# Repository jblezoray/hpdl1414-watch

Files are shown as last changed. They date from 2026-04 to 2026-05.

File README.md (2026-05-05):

# HPDL-1414 Watch

A minimalist watch built around an [HPDL-1414](https://www.datasheetarchive.com/HPDL-1414-datasheet.html) 4-character alphanumeric display, driven by an ATmega32 microcontroller.

If you're brave enougth, you'll find anything you need to build it yourself in this repo.

watch picture

There is a demo of the watch on youtube:

Watch demo video (https://www.youtube.com/watch?v=RL6VkV0jNk0)

## Hardware

| Component | Details |
| --- | --- |
| MCU | atmega328p |
| Display | HPDL-1414 (4 × 16-segment alphanumeric) |
| RTC | DS3231 (I2C) |
| Storage | EEPROM (SPI) |
| Input | 2 buttons |

You'll also need:

- A 3D printer for the case,
- A provider for the HPDL1414 displays. Aliexpress is a good source.
- I ordered the pcbs from jlcpcb. I chose to solder everything myself, but I think it'd be more reasonnable to order with all the components already soldered, except the display as they don't list it.

## Features

- Time display with configurable transitions
- Adjustable luminosity (stored in EEPROM)
- Low-power screen-off state
- State machine architecture

## Project Structure

```
hpdl-1414.ino          # Main sketch
src/
  screen-hpdl1414/     # HPDL-1414 driver
  rtc-ds3231/          # DS3231 RTC driver
  button/              # Button handler
  blinker/             # LED blinker
  persist-configuration/ # EEPROM persistence
  vcc-controller/      # Power control
  states/              # State machine
  pins.h               # Pin definitions
3dmodels/              # Model for the 3D printed case
```

## Watch PCB schematics

Open the schematics (`pcb/hpdl1414/hpdl1414.kicad_sch` and `pcb/hpdl1414/hpdl1414.kicad_pcb`) with [kicad 9.0.1](https://www.kicad.org/).

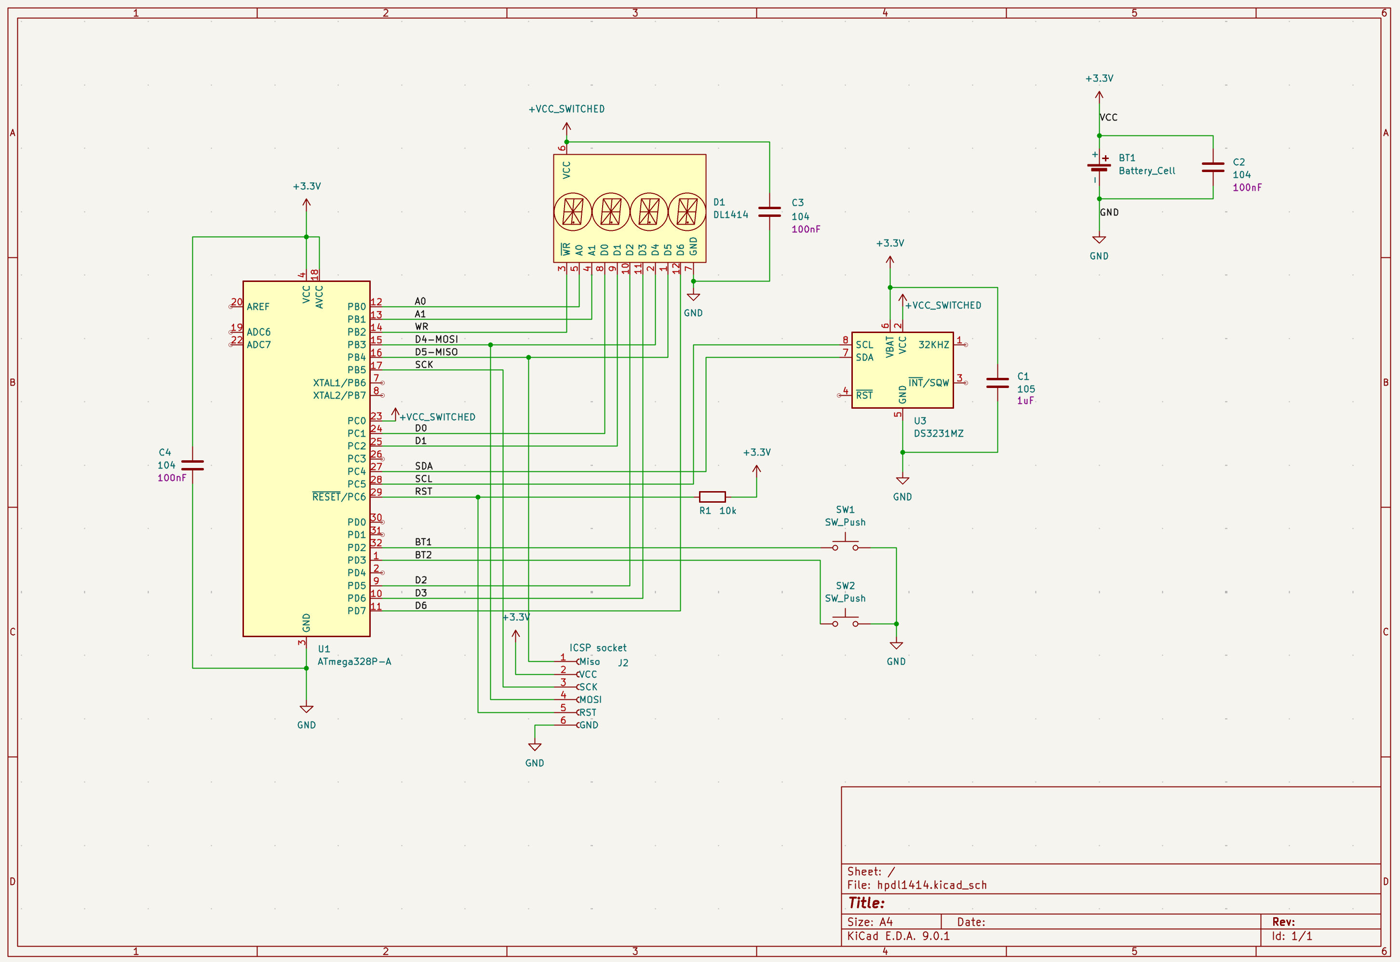
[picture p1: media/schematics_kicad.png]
schematics kicad

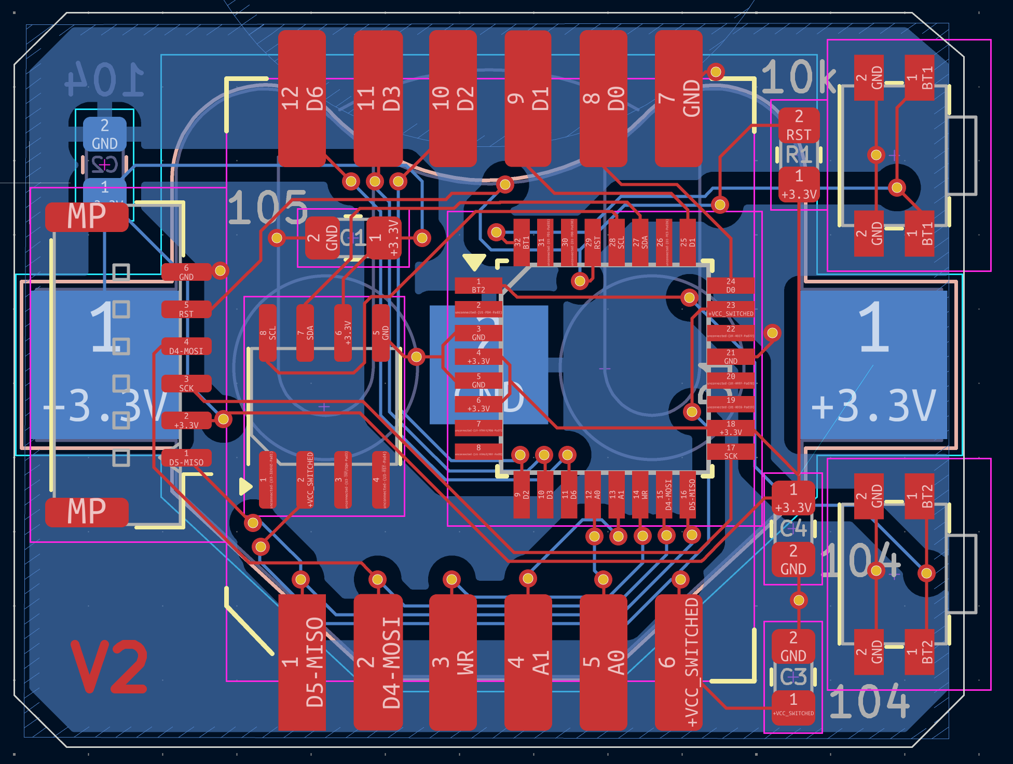
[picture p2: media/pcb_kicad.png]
pcb kicad


Here is the first prototype of the PCB I made. It offers a full view of all the components on one side:
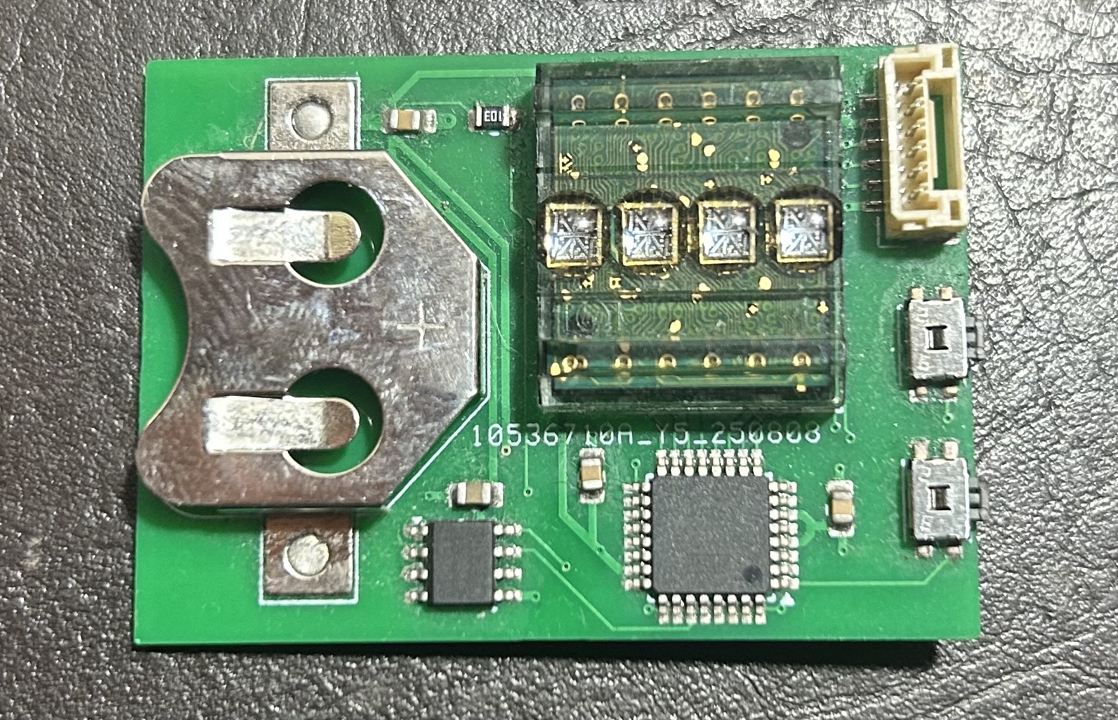
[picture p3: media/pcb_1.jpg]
pcb v1


And here is the final one that is in the watch. It is much smaller:
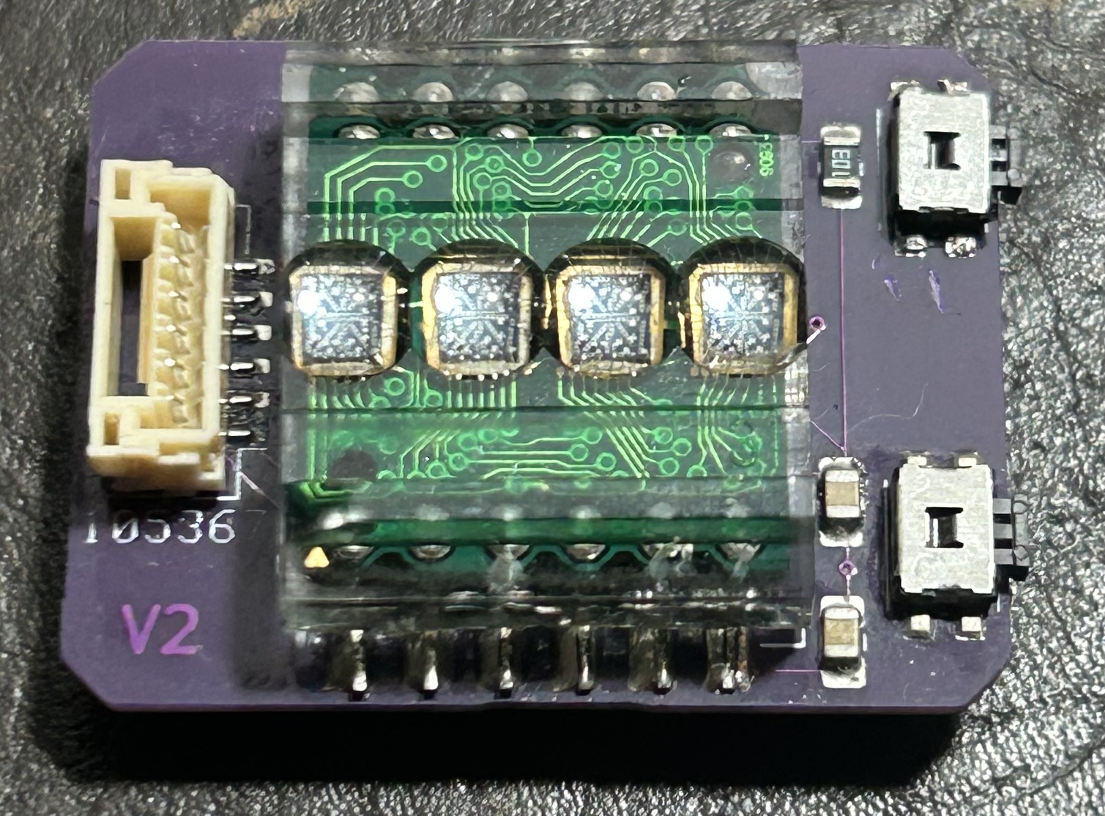
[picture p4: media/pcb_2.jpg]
pcb v2


## Watch case

Open ‘3dmodels/HPDL1414-watch-round.FCStd‘ with [FreeCAD 1.0.2](https://www.freecad.org/). Export it part by part, and print it with your favorite 3d printer. I have great results with a [Bambu lab A1 mini](https://bambulab.com/en-eu/a1-mini).

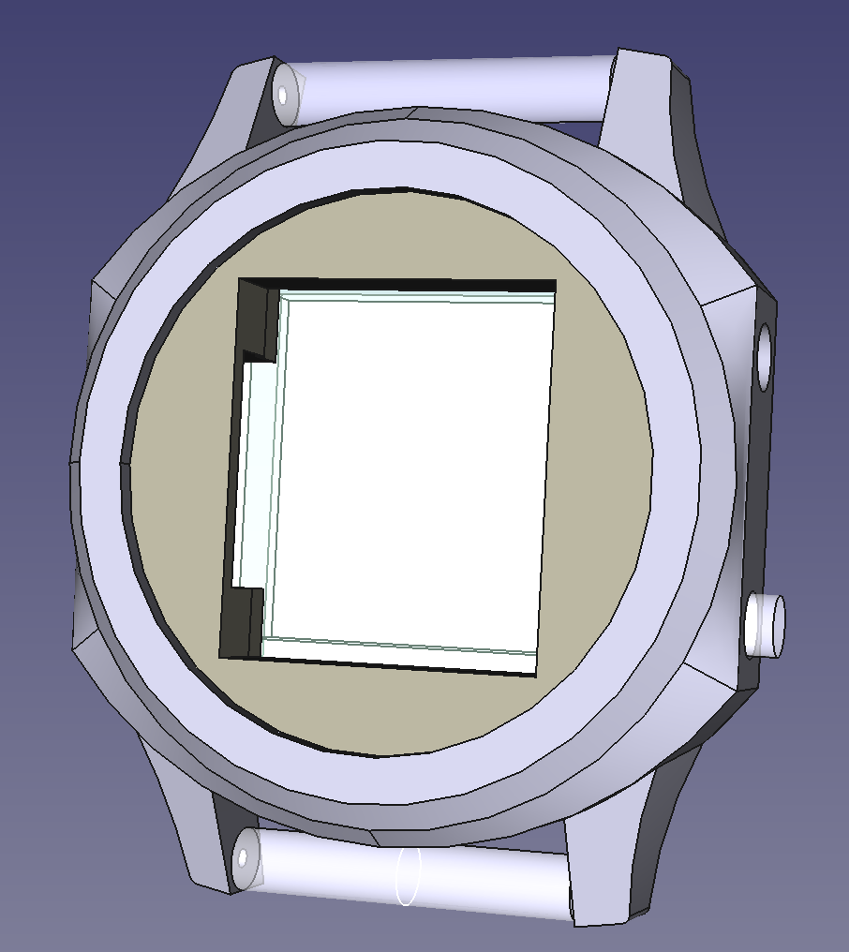
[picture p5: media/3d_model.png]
watch 3d model


You'll have to use threaded inserts, and M1.5 screws to bolt the back of the case:
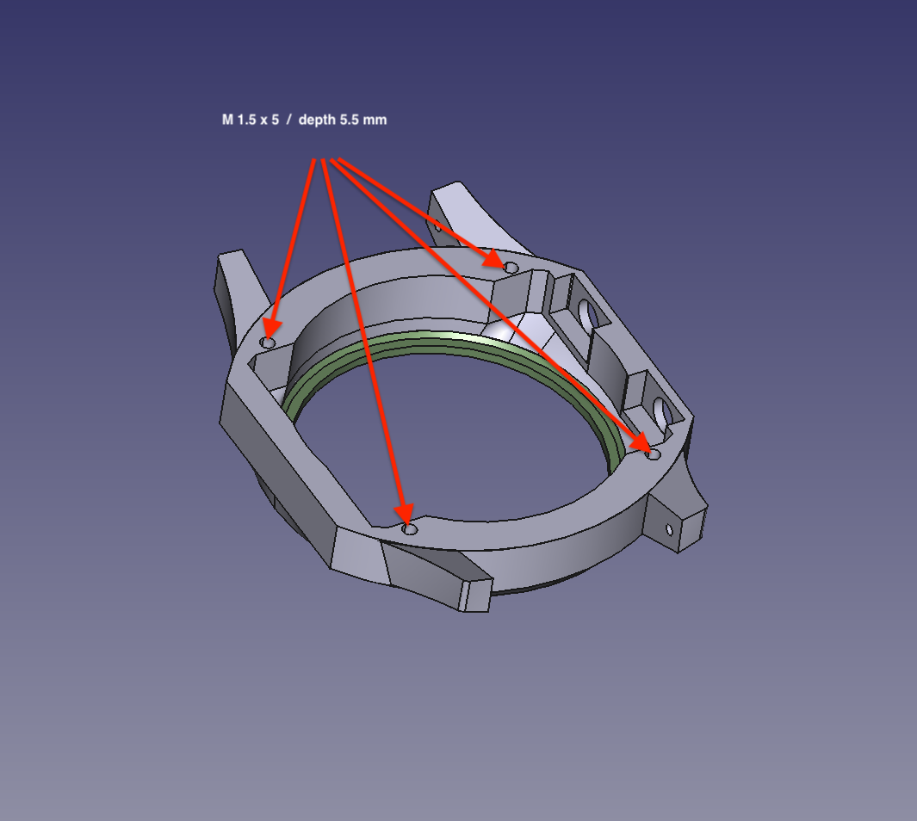
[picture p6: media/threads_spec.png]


## Watch software

I used a Mac for developping this project, but it should work with little to no adjustement on linux. Sorry Windows users, you're on your own on this one.

Also, I find the Arduino IDE really bad, but their libs are ok. So only their CLI is needed. Once installed, everything can be handled by the Makefile.

### Prerequisites

- [Arduino CLI](https://arduino.github.io/arduino-cli/latest/installation/)
- An Arduino board used as ISP programmer (e.g. Uno)

```bash
# Install Arduino CLI (macOS)
$ brew install arduino-cli
$ arduino-cli core install arduino:avr
```

For reference:

```bash
$ arduino-cli version
arduino-cli  Version: 1.4.1 Commit: Homebrew Date: 2026-01-19T16:11:40Z
$ ${HOME}/Library/Arduino15/packages/arduino/tools/avrdude/8.0.0-arduino1/bin/avrdude -v
Avrdude version 8.0-arduino.1
```

### Setup

Copy `config.mk.example` to `config.mk` and fill in your values:

```makefile
ARDUINO_ROOT="/path/to/Arduino15/packages/arduino"  # e.g. ~/Library/Arduino15/packages/arduino
ARDUINO_CLI="/path/to/arduino-cli"
FQBN=arduino:avr:uno      # FQBN of the ISP programmer board
PORT=/dev/cu.usbmodem...  # port of the ISP programmer (make list-devices)
```

### Prepare an arduino to use as an ISP programmer

Plug the board to your computer and run:

```bash
# Flash the ISP programmer
make flash-isp-programmer
```

Now the board can be used as an ISP programmer.

### Plug the watch board to the ISP

IMPORTANT: Remove the battery from the watch board before pluging it!

Plug the ISP and the watch board:

- Arduino ground to GND on the watch board
- PIN 10 to RST
- PIN 11 to MOSI
- PIN 13 to CLK
- 5V to VCC
- PIN 12 to MISO

My working setup:

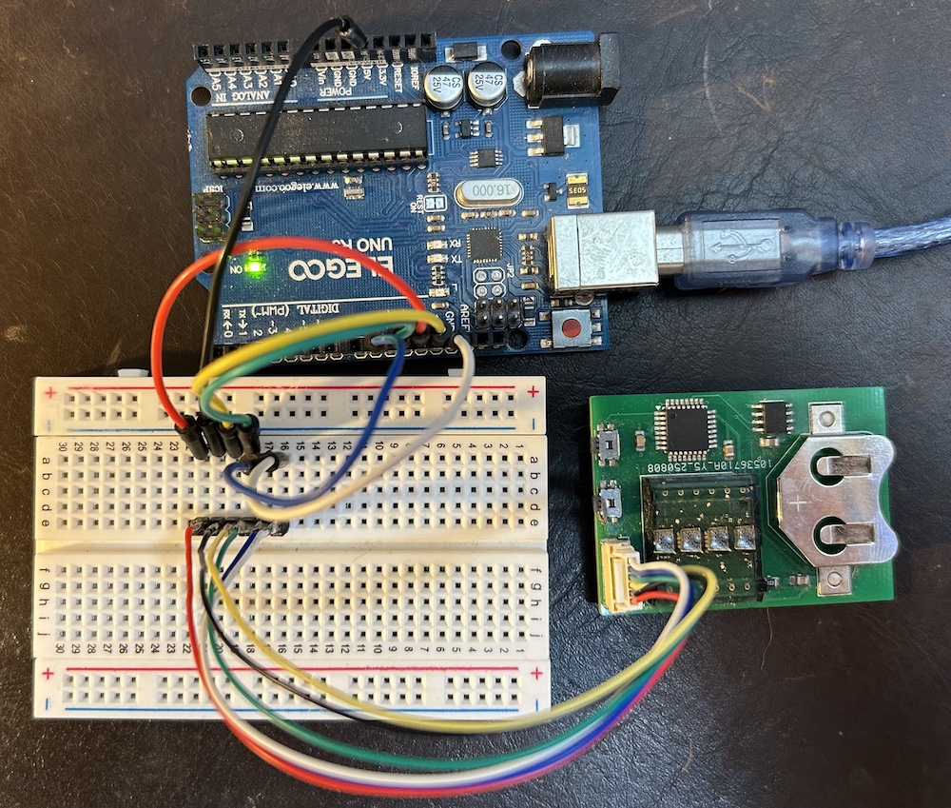
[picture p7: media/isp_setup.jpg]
ISP setup


### Build & Flash

```bash
# First time: Set fuses on the target ATmega32
make set-target-clock-fuses

# Compile and upload the firmware
make upload
```

Run `make help` for all available targets.

## License

MIT

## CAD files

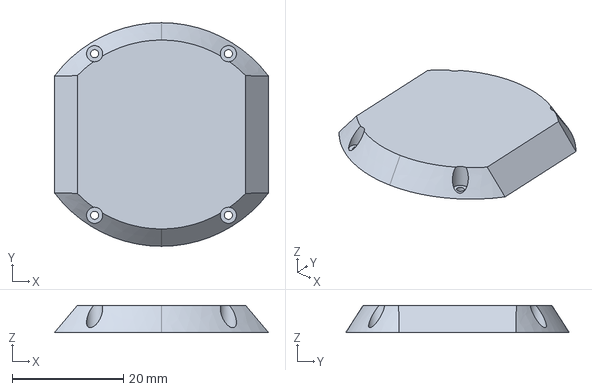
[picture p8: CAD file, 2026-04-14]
3dmodels/HPDL1414-watch-round.FCStd
38.4 x 40.1 x 4.85 mm

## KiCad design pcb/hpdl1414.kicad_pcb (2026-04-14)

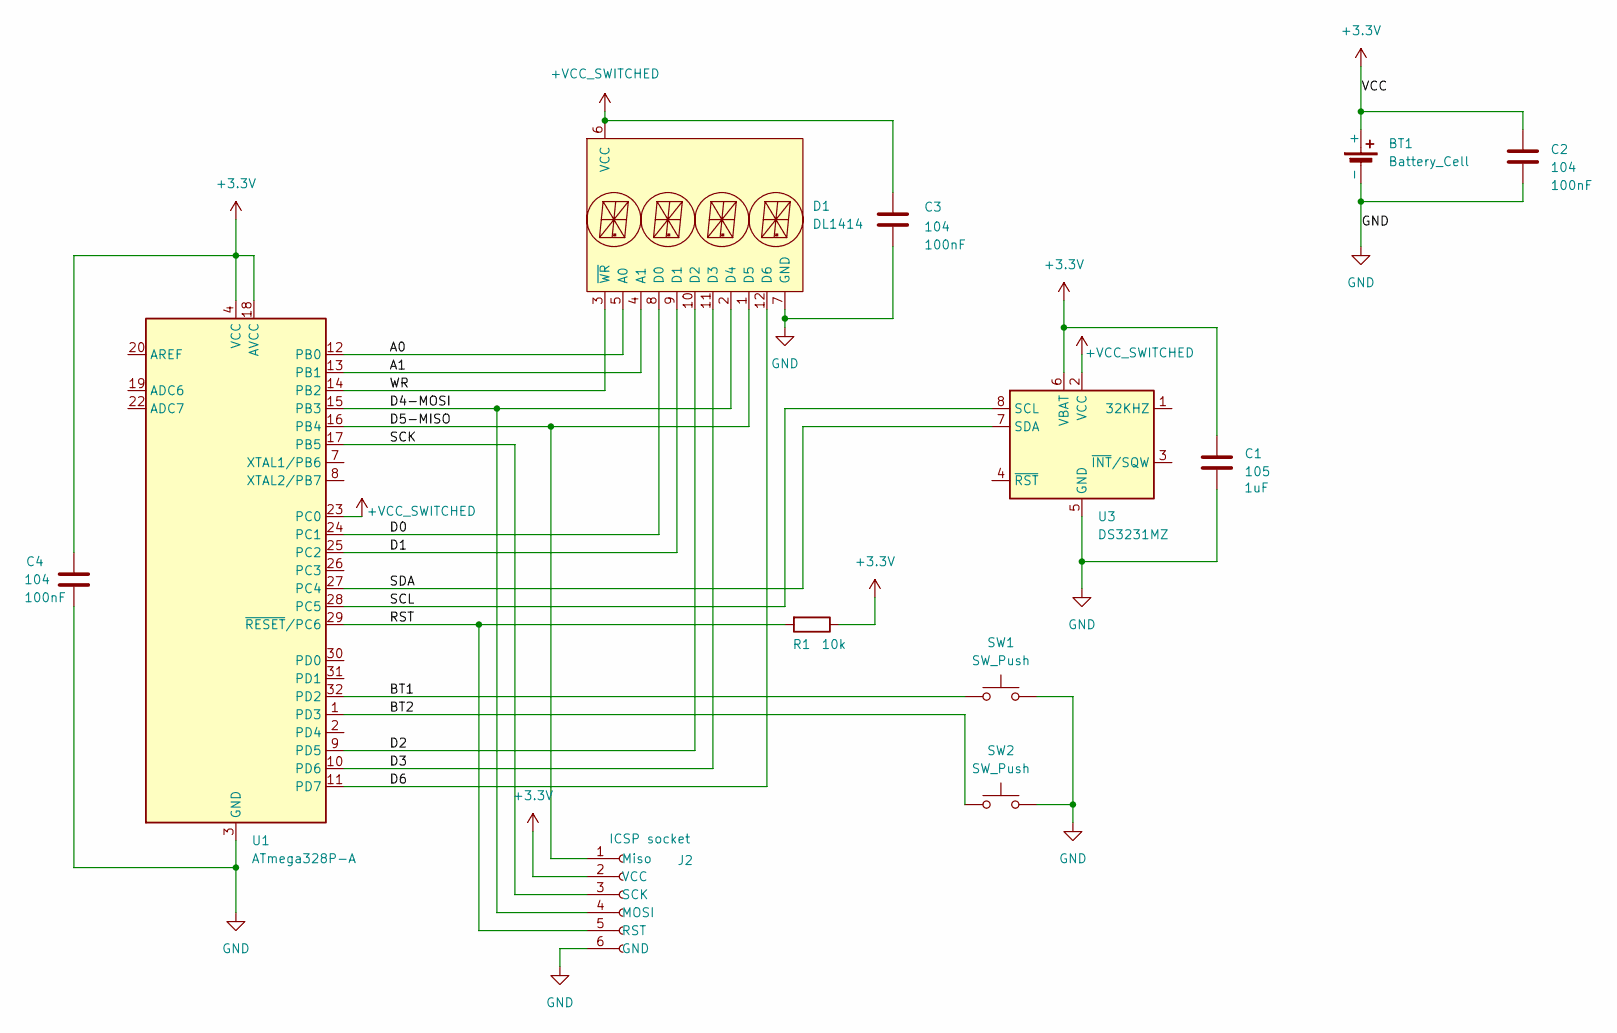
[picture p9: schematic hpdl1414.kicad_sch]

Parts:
BT1: Battery_Cell; BatteryHolder_Multicomp_BC-2001_1x2032
C1: 105; C_0805_2012Metric_Pad1.18x1.45mm_HandSolder
C2, C3, C4: 104; C_0805_2012Metric_Pad1.18x1.45mm_HandSolder
D1: DL1414
J2: ICSP socket; JST_GH_BM06B-GHS-TBT_1x06-1MP_P1.25mm_Vertical
R1: 10k; R_0805_2012Metric_Pad1.20x1.40mm_HandSolder
SW1, SW2: SW_Push; Panasonic_EVQPUJ_EVQPUA
U1: ATmega328P-A; TQFP-32_7x7mm_P0.8mm
U3: DS3231MZ; SOIC-8_3.9x4.9mm_P1.27mm

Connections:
+3.3V: BT1.1 (+), C1.1, C2.1, C4.1, J2.2 (VCC), R1.1, U1.4 (VCC), U1.6 (VCC), U1.18 (AVCC), U3.6 (VBAT)
+VCC_SWITCHED: C3.1, D1.6 (VCC), U1.23 (PC0), U3.2 (VCC)
/A0: D1.5 (A0), U1.12 (PB0)
/A1: D1.4 (A1), U1.13 (PB1)
/BT1: SW1.1, U1.32 (PD2)
/BT2: SW2.1, U1.1 (PD3)
/D0: D1.8 (D0), U1.24 (PC1)
/D1: D1.9 (D1), U1.25 (PC2)
/D2: D1.10 (D2), U1.9 (PD5)
/D3: D1.11 (D3), U1.10 (PD6)
/D4-MOSI: D1.2 (D4), J2.4 (MOSI), U1.15 (PB3)
/D5-MISO: D1.1 (D5), J2.1 (Miso), U1.16 (PB4)
/D6: D1.12 (D6), U1.11 (PD7)
/RST: J2.5 (RST), R1.2, U1.29 (~RESET/PC6)
/SCK: J2.3 (SCK), U1.17 (PB5)
/SCL: U1.28 (PC5), U3.8 (SCL)
/SDA: U1.27 (PC4), U3.7 (SDA)
/WR: D1.3 (~WR), U1.14 (PB2)
GND: BT1.2 (-), C1.2, C2.2, C3.2, C4.2, D1.7 (GND), J2.6 (GND), SW1.2, SW2.2, U1.3 (GND), U1.5 (GND), U1.21 (GND), U3.5 (GND)

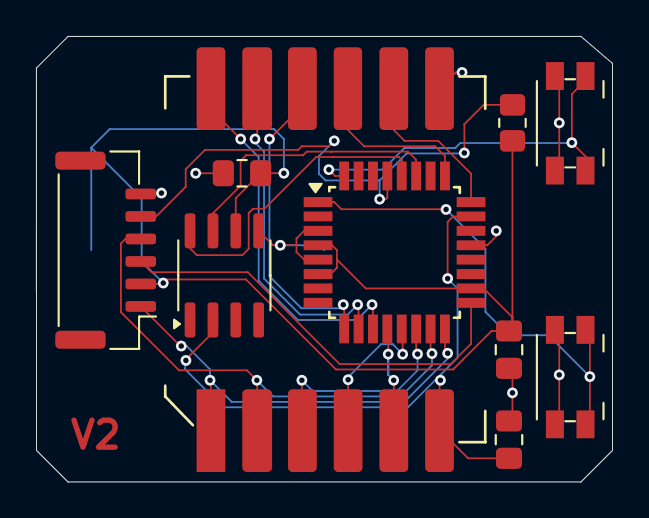
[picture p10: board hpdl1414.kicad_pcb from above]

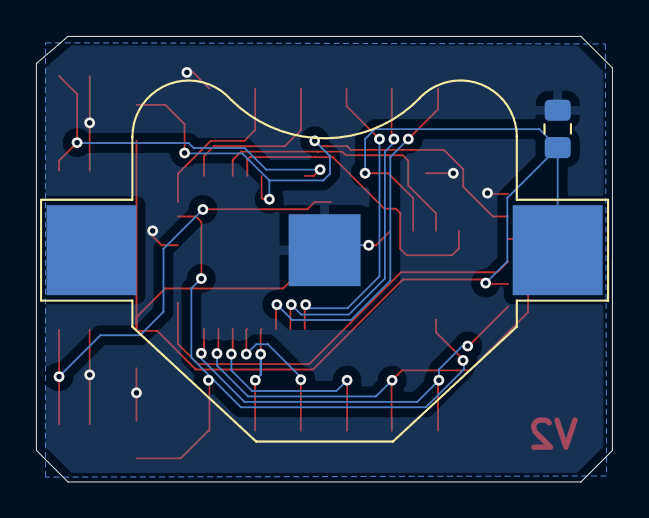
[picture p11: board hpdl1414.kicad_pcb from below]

Board: 2 copper layers, 32.0 x 24.8 mm, 12 parts (2 on the bottom side), 19 nets.

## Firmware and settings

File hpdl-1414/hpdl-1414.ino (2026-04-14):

#include "Arduino.h"
#include "src/screen-hpdl1414/Hpdl1414Writer.h"
#include "src/button/Button.h"
#include "src/blinker/Blinker.h"
#include "src/persist-configuration/Persist.h"
#include "src/persist-configuration/Configuration.h"
#include "src/rtc-ds3231/DS3231.h"
#include "src/vcc-controller/VccController.h"
#include "src/states/state-manager/StateManager.h"
#include "src/states/state-manager/Context.h"
#include "src/pins.h"

const uint8_t ADDRESS_PINS[] = {PIN_A1, PIN_A0};
const uint8_t DATA_PINS[] = {PIN_D0, PIN_D1, PIN_D2, PIN_D3, PIN_D4, PIN_D5, PIN_D6};

Persist<Configuration> persist(PIN_EEPROM);
Hpdl1414Writer hpdl1414(DATA_PINS, ADDRESS_PINS, PIN_WR);
Button bt1(PIN_BT1);
Button bt2(PIN_BT2);
DS3231 rtc;
VccController vccController(PIN_VCC_CONTROLLER);
Blinker blinker(PIN_LED);

StateManager stateManager;
Context context(
  &stateManager,
  &hpdl1414,
  &bt1,
  &bt2,
  &rtc,
  &vccController,
  &persist,
  20, // state update = 50Hz
  2   // screen update = 500Hz
);

bool setup_done = false;

void setup() {
  Wire.begin(); // for DS3231.
  persist.setup();
  if (!persist.is_valid()) {
    Configuration c{MAX_LUMINOSITY, true, true, TransitionCode::TRANSITION_RANDOM_FADE_IN, {'*', '*', '*', '*'}};
    persist.save(c);
  }
  hpdl1414.setup(persist.read().prefered_luminosity);
  bt1.setup();
  bt2.setup();
  stateManager.transition_to(StateCode::STATE_SCREEN_OFF, &context);
  setup_done = true;
}

void loop() {
  if (!setup_done) return;

  uint32_t currentTime = millis();

  if (
    currentTime - context.lastStateUpdateTime >= context.updateStateIntervalMs
    || context.updateStateBurst
  ) {
    context.lastStateUpdateTime = currentTime;
    bt1.update_state();
    bt2.update_state();
    stateManager.in_loop(&context);
  }

  if (
    currentTime - context.lastScreenUpdateTime >= context.updateScreenIntervalMs
    || context.updateScreenBurst
  ) {
    context.lastScreenUpdateTime = currentTime;
    hpdl1414.refresh_screen();
  }

  blinker.update();
}

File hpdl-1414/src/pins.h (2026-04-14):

#ifndef pins_h
#define pins_h

#define PIN_BT1 2
#define PIN_BT2 3
#define PIN_EEPROM 13
#define PIN_LED 13
#define PIN_VCC_CONTROLLER 14

#define PIN_WR 10

#define PIN_A1 9
#define PIN_A0 8

#define PIN_D0 15
#define PIN_D1 16
#define PIN_D2 5
#define PIN_D3 6
#define PIN_D4 11
#define PIN_D5 12
#define PIN_D6 7

#endif

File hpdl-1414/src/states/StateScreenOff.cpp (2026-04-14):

#include "StateScreenOff.h"
#include <avr/sleep.h>
#include "../pins.h"

StateScreenOff::StateScreenOff() {
  _adc_saved_state = 0;
}

void StateScreenOff::disable_ADC() {
    _adc_saved_state = ADCSRA;
    ADCSRA = 0; // disable ADC
}

void StateScreenOff::enable_ADC() {
  if (_adc_saved_state != 0) {
    ADCSRA = _adc_saved_state;
  }
}

// interuption handler
void wake_up() {
  sleep_disable();
  detachInterrupt(digitalPinToInterrupt(PIN_BT1));
  detachInterrupt(digitalPinToInterrupt(PIN_BT2));
}

void StateScreenOff::on_enter(Context* context) {
  context->hpdl1414->set_message("    ");
  context->hpdl1414->set_luminosity(0);

  // switch off VCC on external components
  context->vccController->switch_power_off();

  // disconnect all HPDL1414 pins
  context->hpdl1414->switch_off();

  // disable ADC (analog to digital conversion)
  disable_ADC();

  set_sleep_mode(SLEEP_MODE_PWR_DOWN);

  // timed sequence follows
  noInterrupts();

  attachInterrupt(digitalPinToInterrupt(PIN_BT1), wake_up, FALLING);
  attachInterrupt(digitalPinToInterrupt(PIN_BT2), wake_up, FALLING);
  EIFR = bit(INTF0) | bit(INTF1);  // clear flag for interrupt 0 & 1

  sleep_enable();

  // turn off brown-out enable in software
  // BODS must be set to one and BODSE must be set to zero within four clock cycles
  MCUCR = bit (BODS) | bit (BODSE);
  // The BODS bit is automatically cleared after three clock cycles
  MCUCR = bit (BODS);

  // guarantees next instruction executed
  interrupts();
  // sleep within 3 clock cycles of above
  sleep_cpu();
}

void StateScreenOff::in_loop(Context* context) {
  if (context->bt1->is_pressed_event() || context->bt2->is_pressed_event()) {
    Configuration configuration = context->persist->read();
    context->state_manager->transition_to(StateCode::STATE_SHOW_TIME, context, configuration.switch_on_transition);
  }
}

void StateScreenOff::on_exit(Context* context) {
  // context->hpdl1414->fade_in(context->persist->read().prefered_luminosity);
  context->hpdl1414->switch_on();
  context->vccController->switch_power_on();
  enable_ADC();
}

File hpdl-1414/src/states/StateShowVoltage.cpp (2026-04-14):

#include "StateShowVoltage.h"

StateShowVoltage::StateShowVoltage(
) : MixinTimeoutToScreenOff(5000)
{
  _vcc_millivolts = 0;
  _last_read_time_ms = 0;
}

uint16_t readVccMillivolts() {
  // Set up ADC to read internal 1.1V reference
  // MUX[3:0]=1110, REFS0=1
  ADMUX = (1 << REFS0) | (1 << MUX3) | (1 << MUX2) | (1 << MUX1);
  // Let Vref settle
  delay(2);
  // Start conversion and wait until done.
  ADCSRA |= (1 << ADSC);
  while (ADCSRA & (1 << ADSC));  
  uint16_t result = ADC;
  // 1.1V * 1023 * 1000 (to get mV)
  return (uint16_t)(1125300L / result);
}

// reads a more stable value than the original.
uint16_t readVccMillivoltsAverage(uint8_t samples) {
  uint32_t sum = 0;
  for (uint8_t i = 0; i < samples; i++) {
    sum += readVccMillivolts();
  }
  return (uint16_t)(sum / samples);
}

uint8_t voltageToPercentage(uint16_t voltage) {
  // Clamp voltage to expected range
  if (voltage >= 3000) {
    return 100;
  } else if (voltage <= 1800) {
    return 0;
  }

  // Piecewise linear approximation
  if (voltage > 2900) {
    return min(100, 95 + (voltage - 2900) / 20);  // 2.9–3.0V → 95–100%
  } else if (voltage > 2700) {
    return 75 + (voltage - 2700) / 10;  // 2.7–2.9V → 75–95%
  } else if (voltage > 2200) {
    return 25 + (voltage - 2200) / 10;  // 2.2–2.7V → 25–75%
  } else {
    return max(0, (voltage - 1800) / 16);  // 1.8–2.2V → 0–25%
  }
}

void StateShowVoltage::on_enter(Context* context) {
  MixinTimeoutToScreenOff::on_enter(context);
  if (context->bt2->is_pressed()) {
    context->bt2->ignore_next_released_event();
  }
  if (context->bt1->is_pressed()) {
    context->bt1->ignore_next_released_event();
  }
}

void StateShowVoltage::in_loop(Context* context) {
  MixinTimeoutToScreenOff::in_loop(context);

  uint32_t time = millis();
  if (_last_read_time_ms == 0 || _last_read_time_ms + 1000 < time) {
    _last_read_time_ms = time;
    _vcc_millivolts = readVccMillivoltsAverage(10);
  }

  char the_string[5];
  if (context->persist->read().voltage_in_percentage) {
    uint8_t percentage = voltageToPercentage(_vcc_millivolts);
    snprintf(
      the_string,
      sizeof(the_string),
      "%3u%%",
      percentage
    );
  } else {
    snprintf(
      the_string,
      sizeof(the_string),
      "%1u.%1uV",
      _vcc_millivolts / 1000,
      (_vcc_millivolts % 1000) / 100
    );
  }

  context->hpdl1414->set_message(the_string);

  if (context->bt1->is_released_event()) {
    Configuration conf = context->persist->read();
    conf.voltage_in_percentage = ! conf.voltage_in_percentage;
    context->persist->save(conf);
  }
  if (context->bt2->is_released_event()) {
    context->state_manager->transition_to(StateCode::STATE_SHOW_TIME, context);
  }
}

void StateShowVoltage::on_exit(Context* context) {
  MixinTimeoutToScreenOff::on_exit(context);
}

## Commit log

2026-04-14 source code
    [Configuration.h]
2026-04-14 3d models
    [HPDL1414-watch-round.FCStd]
